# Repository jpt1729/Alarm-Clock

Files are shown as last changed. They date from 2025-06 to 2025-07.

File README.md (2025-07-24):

# Alarm-Clock

Custom built alarm clock. I was partly inspired by this https://busy.bar/. I also just wanted ot make a cool custom project and right now I only have an Alexa next to my bed so I can't actually see the current time, but with this it should both wake me up and it should tell me the time :) 

What this basically is its an ESP32 controlled alarm clock that connects to Wifi has a 1.9" LCD display and a snooze bar. It serves as a clock and an alarm (as of now, but I want to program it a bit more in the future!)

When I first learned about making PCBs this (along with a keyboard [which I already made!]) was one of the projects I wanted to try my hand at so I am happy I got to do it!

The plan to make the case a bit easier to print is to print the top part out and then the bottom part out and connect the two with a soldering iron. This will use a lot less plastic (if not I will basically be printing a solid block of plastic).

# Photos






# BOM

| Item | Quantity Used | Quantity Purchased | Designator | Part Number / Description | Link | Cost |
|---|---|---|---|---|---|---|
| Case | 1 | | | Custom Case | | |
| PCB | 1 | 5 | | Custom PCB | | $8.90 |
| JST Connector | 4 | 5 | | JST-XH-A 5 | [LCSC](https://lcsc.com/product-detail/Wire-To-Board-Connector_JST-B5B-XH-A-LF-SN_C157991.html) | $0.42 |
| JST Connector | 2 | 5 | | JST-XH-A 8 | [LCSC](https://lcsc.com/product-detail/Wire-To-Board-Connector_JST-B8B-XH-A-LF-SN_C157972.html) | $0.66 |
| MCU | 1 | 1 | | ESP-32-S3-MINI-1 | [LCSC](https://lcsc.com/product-detail/WiFi-Modules_Espressif-Systems-ESP32-S3-MINI-1-N8_C2913206.html) | $5.11 |
| Buzzer | 2 | 5 | | TMB12A05 | [LCSC](https://lcsc.com/product-detail/Buzzers_Jiangsu-Huaneng-Elec-TMB12A05_C96093.html) | $0.90 |
| Capacitor | 1 | 100 | C1 | 0603 1uF (100nF) | [LCSC](https://lcsc.com/product-detail/image/CC0603KRX7R9BB104_C14663.html) | $0.24 |
| USB Connector | 1 | 1 | J1 | USB-C USB4105-GF-A | [LCSC](https://lcsc.com/product-detail/USB-Connectors_Global-Connector-Technology-USB4105-GF-A_C3020560.html) | $1.16 |
| LCD Display | 1 | 10 | | 1.9" LCD | [AliExpress](https://www.aliexpress.us/item/3256807182983606.html) | $3.25 |
| Diodes | 2 | 10 | | 40V 200mA NPN TO-92 | [LCSC](https://lcsc.com/product-detail/image/2N3904X_C5156722.html) | $0.38 |
| Resistor | 1 | 100 | R1 | 10k Ohm 0603 | [LCSC](https://lcsc.com/product-detail/image/RC0603FR-0710KL_C98220.html) | $0.11 |
| Resistor | 2 | 100 | R2, R3 | 5.1k Ohm 0603 | [LCSC](https://lcsc.com/product-detail/image/RC0603FR-075K1L_C105580.html) | $0.12 |
| Resistor | 2 | 100 | R4, R5 | 1k Ohm 0603 | [LCSC](https://lcsc.com/product-detail/Chip-Resistor-Surface-Mount_YAGEO-RC0603FR-071KL_C22548.html) | $0.11 |
| Switch | 1 | 10 | SW1 | Gateron Low Profile | [AliExpress](https://www.aliexpress.us/item/3256808635477539.html) | $5.79 |
| Encoder | 1 | 5 | ENC1 | EC11 Rotary Encoder | [AliExpress](https://www.aliexpress.us/item/3256801237549169.html) | $0.99 |
| Voltage Regulator | 1 | 5 | U1 | AMS1117-3.3 | [LCSC](https://lcsc.com/product-detail/Voltage-Regulators-Linear-Low-Drop-Out-LDO-Regulators_Advanced-Monolithic-Systems-AMS1117-3-3_C6186.html) | $0.87 |
| SXH-001T-P0.6 | | 100 | | Terminal pin (x100) | [LCSC](https://lcsc.com/product-detail/Housing-Contact_JST-SXH-001T-P0-6_C140573.html) | $1.08 |
| XHP-5 | | 20 | | 5-pin housing (x20) | [LCSC](https://lcsc.com/product-detail/Housings-Wire-To-Board-Wire-To-Wire_JST-XHP-5_C144404.html) | $0.46 |
| XHP-8 | | 20 | | 8-pin housing (x20) | [LCSC](https://lcsc.com/product-detail/Housings-Wire-To-Board-Wire-To-Wire_JST-XHP-8_C144407.html) | $0.65 |
| Connector Kit (Amazon) | | | | SXH-001T-P0.6, XHP-5, XHP-8 Assortment | [Amazon](https://a.co/d/gTI01NR) | $6.97 |
| Shipping JLC PCB | | | | | | $22.73 |
| Shipping LCSC | | | | | | $17.39 |
| Shipping AliExpress | | | | | | $0.00 |
| Hotplate | 1 | 1 | | Soldering Hotplate | [AliExpress](https://www.aliexpress.us/item/3256806325004979.html) | $20.05 |
| **Total** | | | | | | **$77.72** |

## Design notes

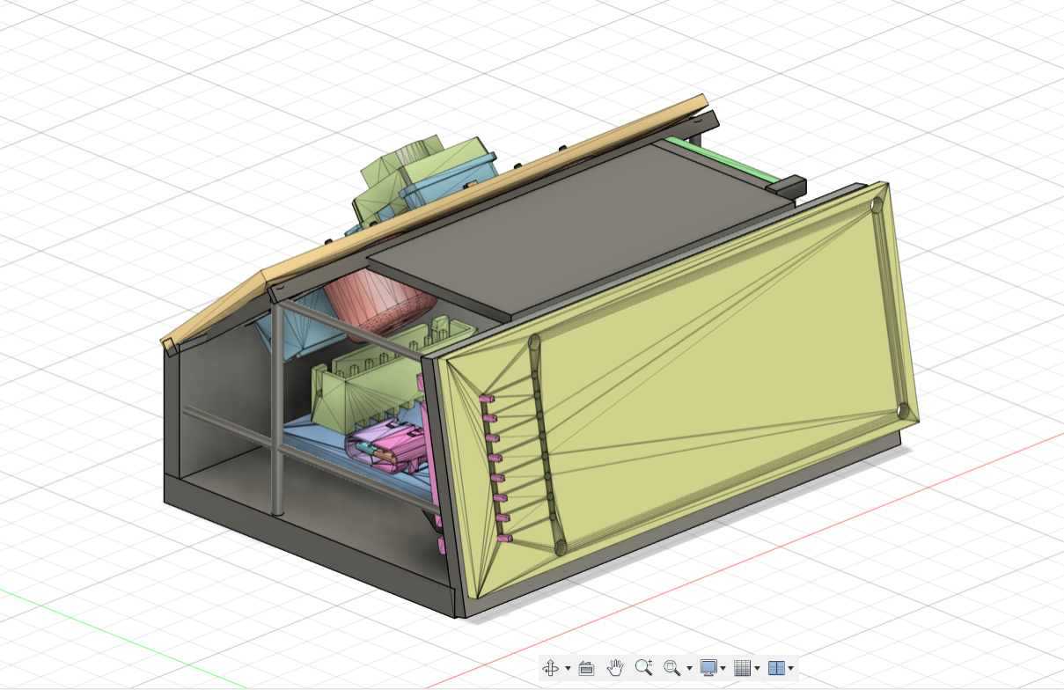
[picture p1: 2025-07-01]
photos/Screenshot 2025-07-01 144503.png

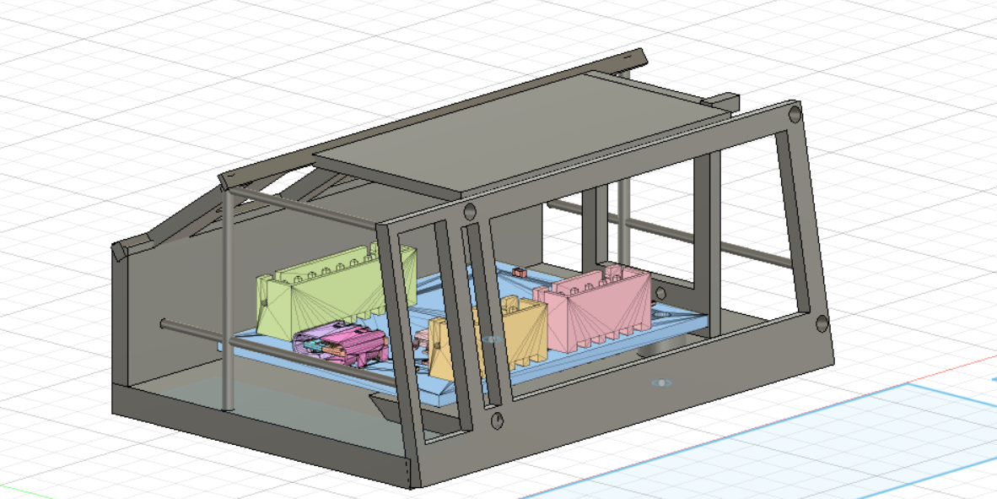
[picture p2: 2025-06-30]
photos/Screenshot 2025-06-30 102602.png

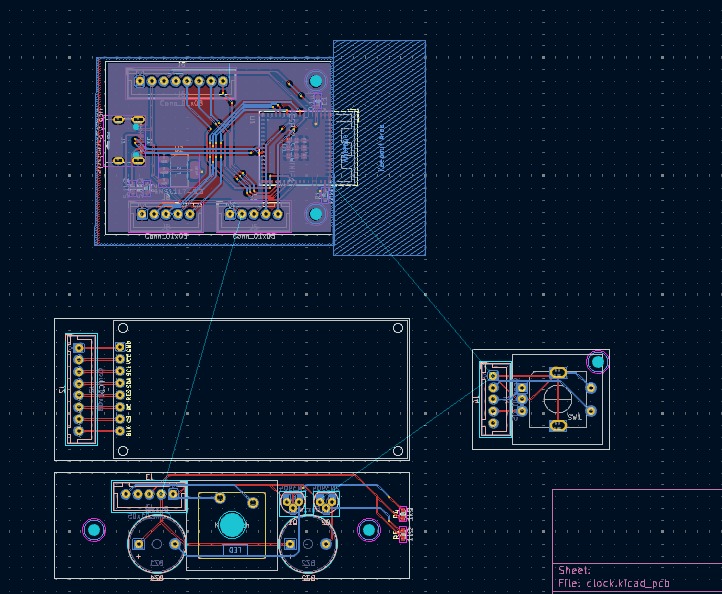
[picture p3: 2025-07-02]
photos/Screenshot 2025-07-01 180052.png

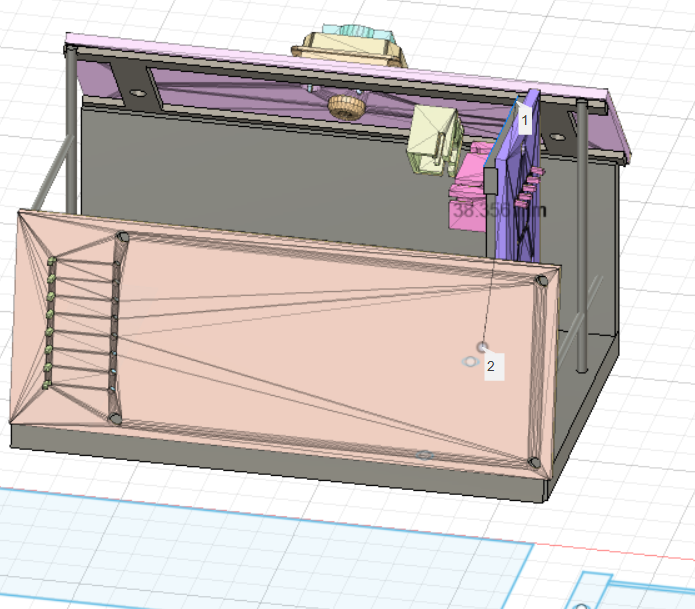
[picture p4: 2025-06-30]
photos/Screenshot 2025-06-30 092751.png

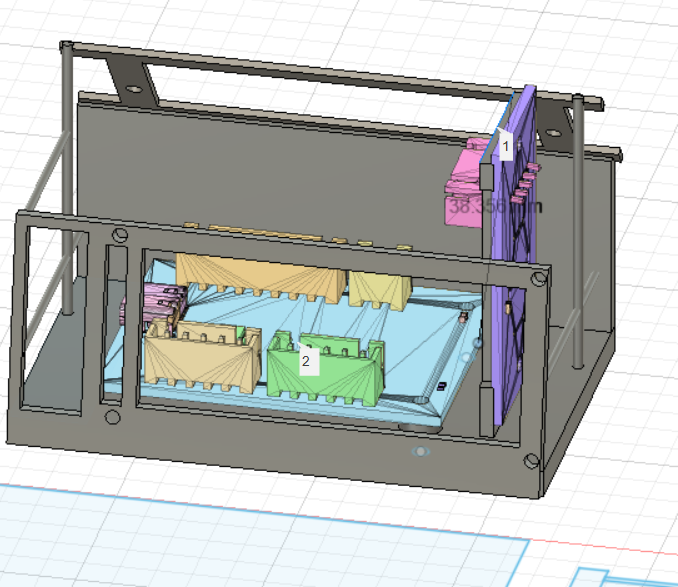
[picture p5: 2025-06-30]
photos/Screenshot 2025-06-30 092739.png

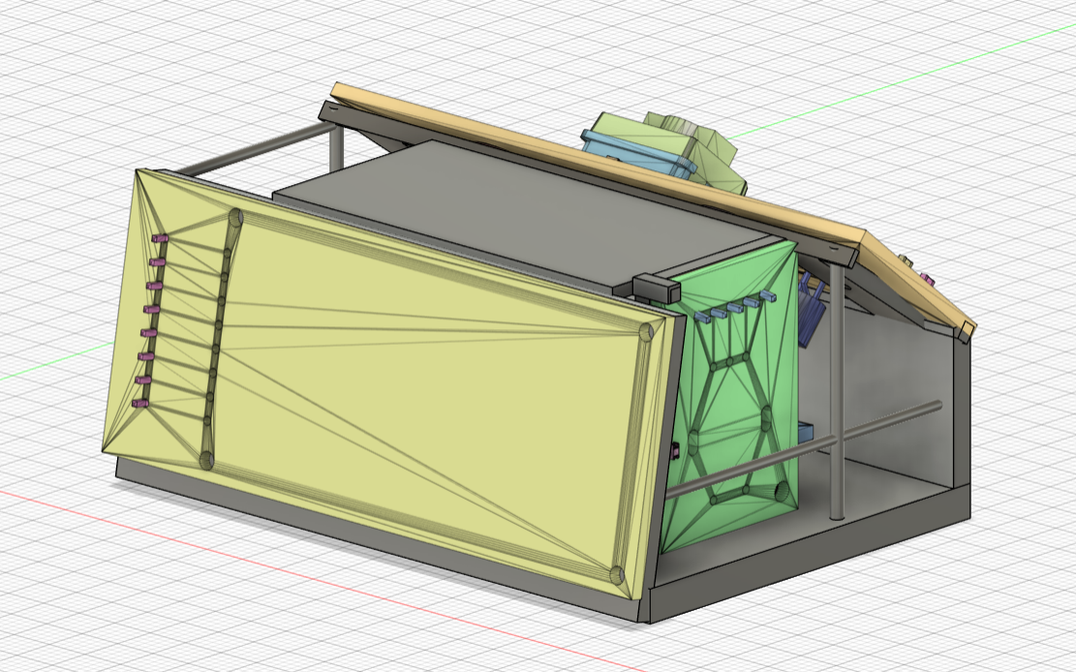
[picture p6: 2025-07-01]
photos/Screenshot 2025-07-01 144437.png

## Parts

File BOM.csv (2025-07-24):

Item | Quantity Used | Quantity Purchased | Designator | Part Number / Description | Link | Cost
Case | 1 |  |  | Custom Case
PCB | 1 | 5 |  | Custom PCB |  | $8.90
JST Connector | 4 | 5 |  | JST-XH-A 5 | https://lcsc.com/product-detail/Wire-To-Board-Connector_JST-B5B-XH-A-LF-SN_C157991.html | $0.42
JST Connector | 2 | 5 |  | JST-XH-A 8 | https://www.google.com/search | $0.66
MCU | 1 | 1 |  | ESP-32-S3-MINI-1 | https://lcsc.com/product-detail/WiFi-Modules_Espressif-Systems-ESP32-S3-MINI-1-N8_C2913206.html | $5.11
Buzzer | 2 | 5 |  | TMB12A05 | https://lcsc.com/product-detail/Buzzers_Jiangsu-Huaneng-Elec-TMB12A05_C96093.html | $0.90
Capacitor | 1 | 100 | C1 | 0603 1uF (100nF) | https://lcsc.com/product-detail/image/CC0603KRX7R9BB104_C14663.html | $0.24
USB Connector | 1 | 1 | J1 | USB-C USB4105-GF-A | https://www.google.com/search | $1.16
LCD Display | 1 | 10 |  | 1.9" LCD | https://www.aliexpress.us/item/3256807182983606.html | $3.25
Diodes | 2 | 10 |  | 40V 200mA NPN TO-92 | https://lcsc.com/product-detail/image/2N3904X_C5156722.html | $0.38
Resistor | 1 | 100 | R1 | 10k Ohm 0603 | https://lcsc.com/product-detail/image/RC0603FR-0710KL_C98220.html | $0.11
Resistor | 2 | 100 | R2, R3 | 5.1k Ohm 0603 | https://lcsc.com/product-detail/image/RC0603FR-075K1L_C105580.html | $0.12
Resistor | 2 | 100 | R4, R5 | 1k Ohm 0603 | https://lcsc.com/product-detail/Chip-Resistor-Surface-Mount_YAGEO-RC0603FR-071KL_C22548.html | $0.11
Switch | 1 | 10 | SW1 | Gateron Low Profile | https://www.aliexpress.us/item/3256808635477539.html | $5.79
Encoder | 1 | 5 | ENC1 | EC11 Rotary Encoder | https://www.aliexpress.us/item/3256801237549169.html | $0.99
Voltage Regulator | 1 | 5 | U1 | AMS1117-3.3 | https://lcsc.com/product-detail/Voltage-Regulators-Linear-Low-Drop-Out-LDO-Regulators_Advanced-Monolithic-Systems-AMS1117-3-3_C6186.html | $0.87
SXH-001T-P0.6 |  | 100 |  | Terminal pin (x100) | https://lcsc.com/product-detail/Housing-Contact_JST-SXH-001T-P0-6_C140573.html | $1.08
XHP-5 |  | 20 |  | 5-pin housing (x20) | https://lcsc.com/product-detail/Housings-Wire-To-Board-Wire-To-Wire_JST-XHP-5_C144404.html | $0.46
XHP-8 |  | 20 |  | 8-pin housing (x20) | https://lcsc.com/product-detail/Housings-Wire-To-Board-Wire-To-Wire_JST-XHP-8_C144407.html | $0.65
Connector Kit (Amazon) |  |  |  |  | SXH-001T-P0.6 | XHP-5 | XHP-8 Assortment | https://a.co/d/gTI01NR | $6.97
Hotplate | 1 | 1 |  | Soldering Hotplate | https://www.aliexpress.us/item/3256806325004979.html | $20.05
Shipping JLC PCB |  |  |  |  |  | $22.73
Shipping LCSC |  |  |  |  |  | $17.39
Shipping AliExpress |  |  |  |  |  | $0.00
Total |  |  |  |  |  | $77.72

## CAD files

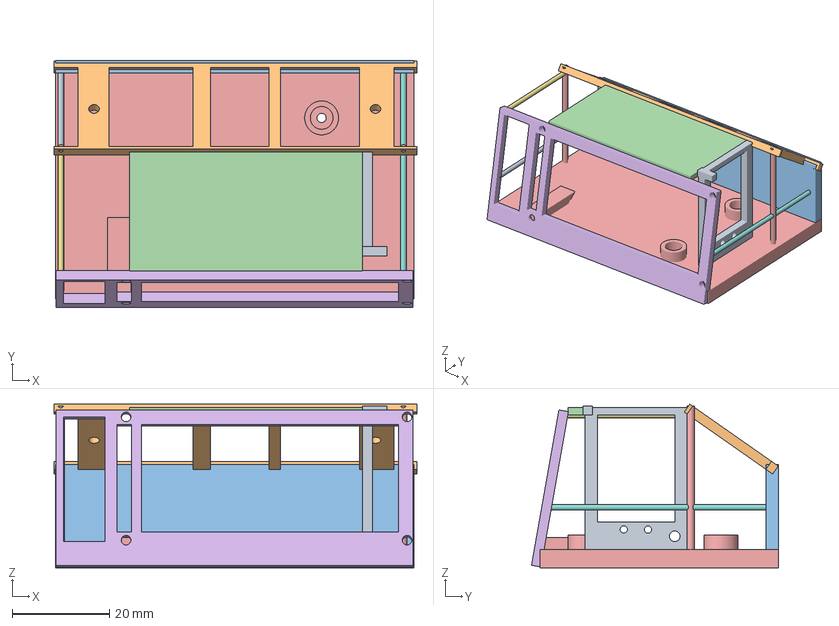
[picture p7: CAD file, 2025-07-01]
CAD/case.3mf
74.8 x 50.9 x 33.7 mm

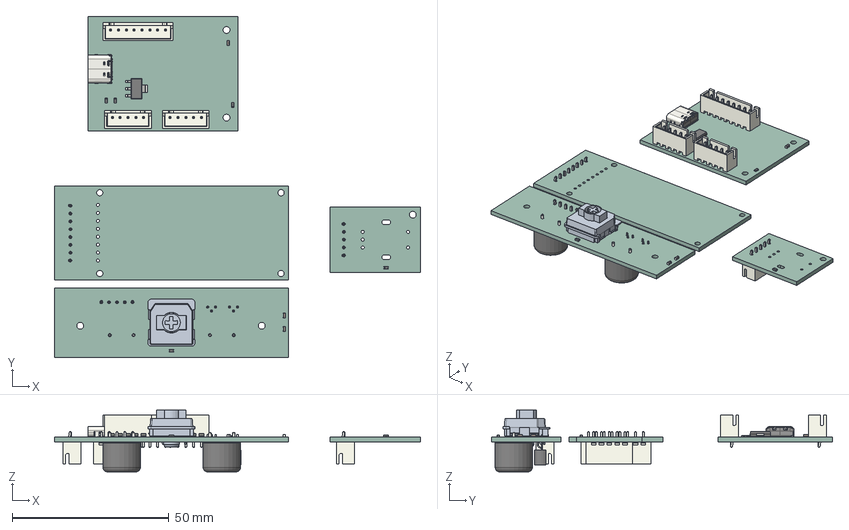
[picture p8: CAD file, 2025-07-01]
PCB/clock.step
117.0 x 108.9 x 19.8 mm
clock 1.1.1
D_0603_1608Metric x 2
JST_XH_B5B-XH-A_1x05_P2.50mm_Vertical x 4
C_0603_1608Metric x 3
JST_XH_B8B-XH-A_1x08_P2.50mm_Vertical x 2
R_0603_1608Metric x 3
SOT-223
USB_C_Receptacle_GCT_USB4105-xx-A_16P_TopMnt_Horizontal
TO-92 x 2
Buzzer_12x9.5RM7.6 x 2
clock_PCB_1
clock_PCB_2
clock_PCB_3
clock_PCB_4

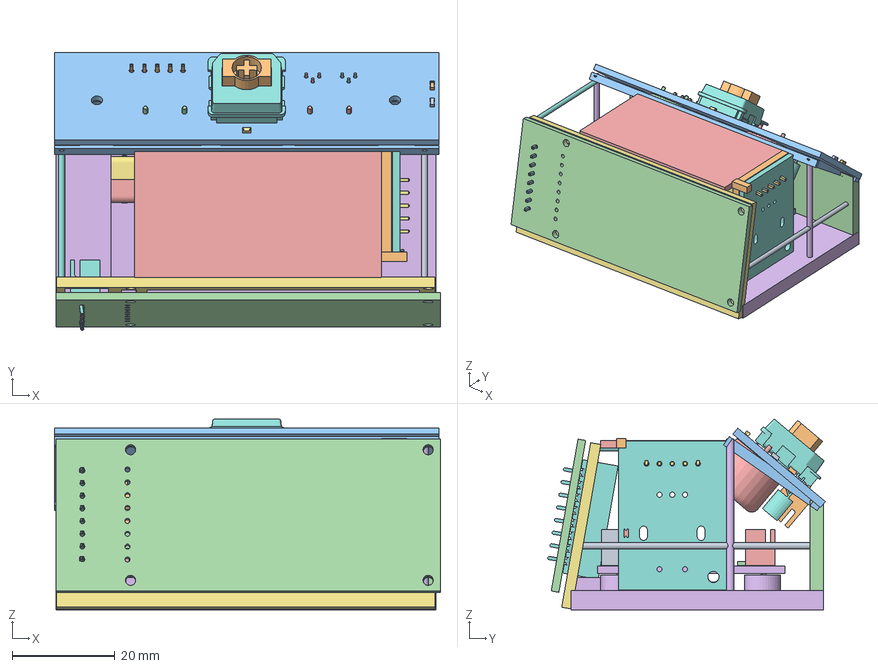
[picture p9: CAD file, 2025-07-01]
CAD/clock+pcb.3mf
75.1 x 54.1 x 37.2 mm
clock_PCB_2
D_0603_1608Metric (1)
clock_PCB_3
C_0603_1608Metric (1)
SOT-223
TO-92 (1)
R_0603_1608Metric (2)
R_0603_1608Metric
JST_XH_B5B-XH-A_1x05_P2.50mm_Vertical (3)
JST_XH_B8B-XH-A_1x08_P2.50mm_Vertical
JST_XH_B8B-XH-A_1x08_P2.50mm_Vertical (1)
Buzzer_12x9.5RM7.6 (1)
JST_XH_B5B-XH-A_1x05_P2.50mm_Vertical
C_0603_1608Metric (2)
D_0603_1608Metric
C_0603_1608Metric
JST_XH_B5B-XH-A_1x05_P2.50mm_Vertical (1)
clock_PCB_1
Buzzer_12x9.5RM7.6
clock_PCB_4
JST_XH_B5B-XH-A_1x05_P2.50mm_Vertical (2)
TO-92
R_0603_1608Metric (1)

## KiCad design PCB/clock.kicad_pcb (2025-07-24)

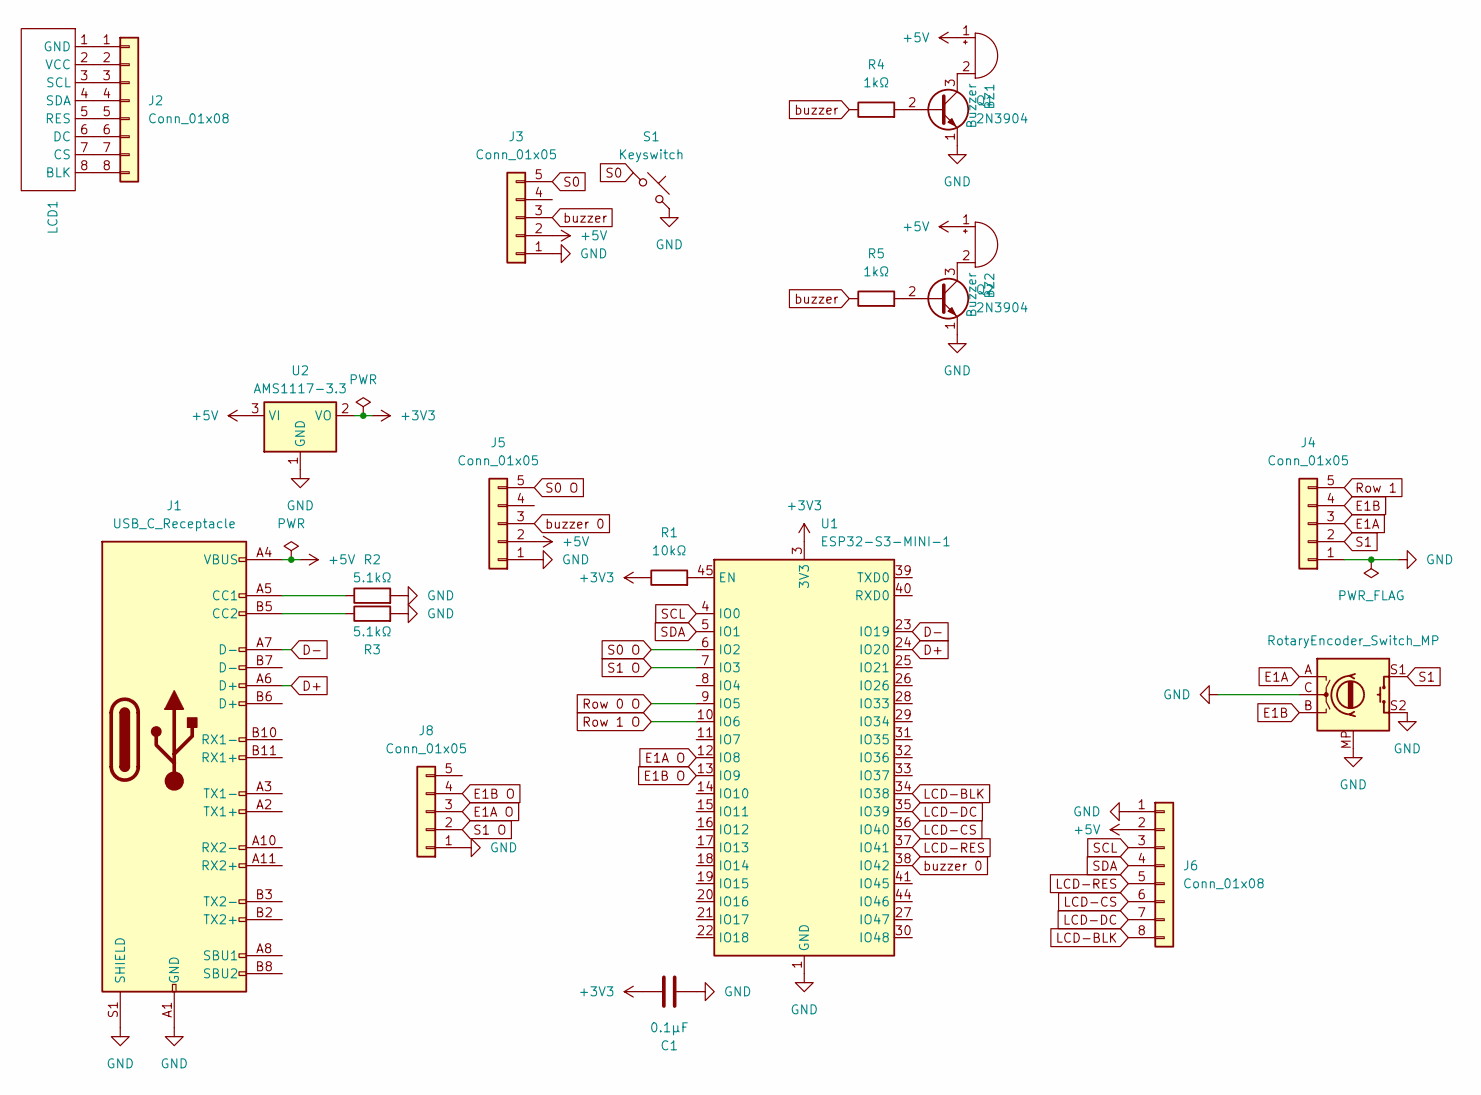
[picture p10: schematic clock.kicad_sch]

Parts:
BZ1, BZ2: Buzzer; Buzzer_12x9.5RM7.6
C1: 0.1µF; C_0603_1608Metric_Pad1.08x0.95mm_HandSolder
J1: USB_C_Receptacle; USB_C_Receptacle_GCT_USB4105-xx-A_16P_TopMnt_Horizontal
J2, J6: Conn_01x08; JST_XH_B8B-XH-A_1x08_P2.50mm_Vertical
J3, J4, J5, J8: Conn_01x05; JST_XH_B5B-XH-A_1x05_P2.50mm_Vertical
LCD1: TZT_1.9in_TFT_ST7789
Q1, Q2: 2N3904; TO-92_HandSolder
R1: 10kΩ; R_0603_1608Metric_Pad0.98x0.95mm_HandSolder
R2, R3: 5.1kΩ; R_0603_1608Metric_Pad0.98x0.95mm_HandSolder
R4, R5: 1kΩ; C_0603_1608Metric_Pad1.08x0.95mm_HandSolder
S1: Keyswitch; SW_KS33_1u
SW1: RotaryEncoder_Switch_MP; Encoder_EC11_MX
U1: ESP32-S3-MINI-1; ESP32-S2-MINI-1
U2: AMS1117-3.3; SOT-223-3_TabPin2

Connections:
+3V3: C1.2, R1.1, U1.3 (3V3), U2.2 (VO)
+5V: BZ1.1 (+), BZ2.1 (+), J1.A4 (VBUS), J1.A9 (VBUS), J1.B4 (VBUS), J1.B9 (VBUS), J3.2, J5.2, J6.2, U2.3 (VI)
D+: J1.A6 (D+), U1.24 (IO20)
D-: J1.A7 (D-), U1.23 (IO19)
E1A: J4.3, SW1.A
E1A O: J8.3, U1.12 (IO8)
E1B: J4.4, SW1.B
E1B O: J8.4, U1.13 (IO9)
GND: C1.1, J1.A1 (GND), J1.A12 (GND), J1.B1 (GND), J1.B12 (GND), J1.S1 (SHIELD), J3.1, J4.1, J5.1, J6.1, J8.1, Q1.1 (E), Q2.1 (E), R2.2, R3.2, S1.2, SW1.C, SW1.MP, SW1.S2, U1.1 (GND), U1.2 (GND), U1.42 (GND), U1.43 (GND), U1.46 (GND), U1.47 (GND), U1.48 (GND), U1.49 (GND), U1.50 (GND), U1.51 (GND), U1.52 (GND), U1.53 (GND), U1.54 (GND), U1.55 (GND), U1.56 (GND), U1.57 (GND), U1.58 (GND), U1.59 (GND), U1.60 (GND), U1.61 (GND), U1.62 (GND), U1.63 (GND), U1.64 (GND), U1.65 (GND), U2.1 (GND)
LCD-BLK: J6.8, U1.34 (IO38)
LCD-CS: J6.6, U1.36 (IO40)
LCD-DC: J6.7, U1.35 (IO39)
LCD-RES: J6.5, U1.37 (IO41)
unnamed: BZ1.2 (-), Q1.3 (C)
unnamed: BZ2.2 (-), Q2.3 (C)
unnamed: J1.A5 (CC1), R2.1
unnamed: J1.B5 (CC2), R3.1
unnamed: J2.1, LCD1.1 (GND)
unnamed: J2.2, LCD1.2 (VCC)
unnamed: J2.3, LCD1.3 (SCL)
unnamed: J2.4, LCD1.4 (SDA)
unnamed: J2.5, LCD1.5 (RES)
unnamed: J2.6, LCD1.6 (DC)
unnamed: J2.7, LCD1.7 (CS)
unnamed: J2.8, LCD1.8 (BLK)
unnamed: Q1.2 (B), R4.2
unnamed: Q2.2 (B), R5.2
unnamed: R1.2, U1.45 (EN)
Row 0 O: U1.9 (IO5)
Row 1: J4.5
Row 1 O: U1.10 (IO6)
S0: J3.5, S1.1
S0 O: J5.5, U1.6 (IO2)
S1: J4.2, SW1.S1
S1 O: J8.2, U1.7 (IO3)
SCL: J6.3, U1.4 (IO0)
SDA: J6.4, U1.5 (IO1)
buzzer: J3.3, R4.1, R5.1
buzzer 0: J5.3, U1.38 (IO42)

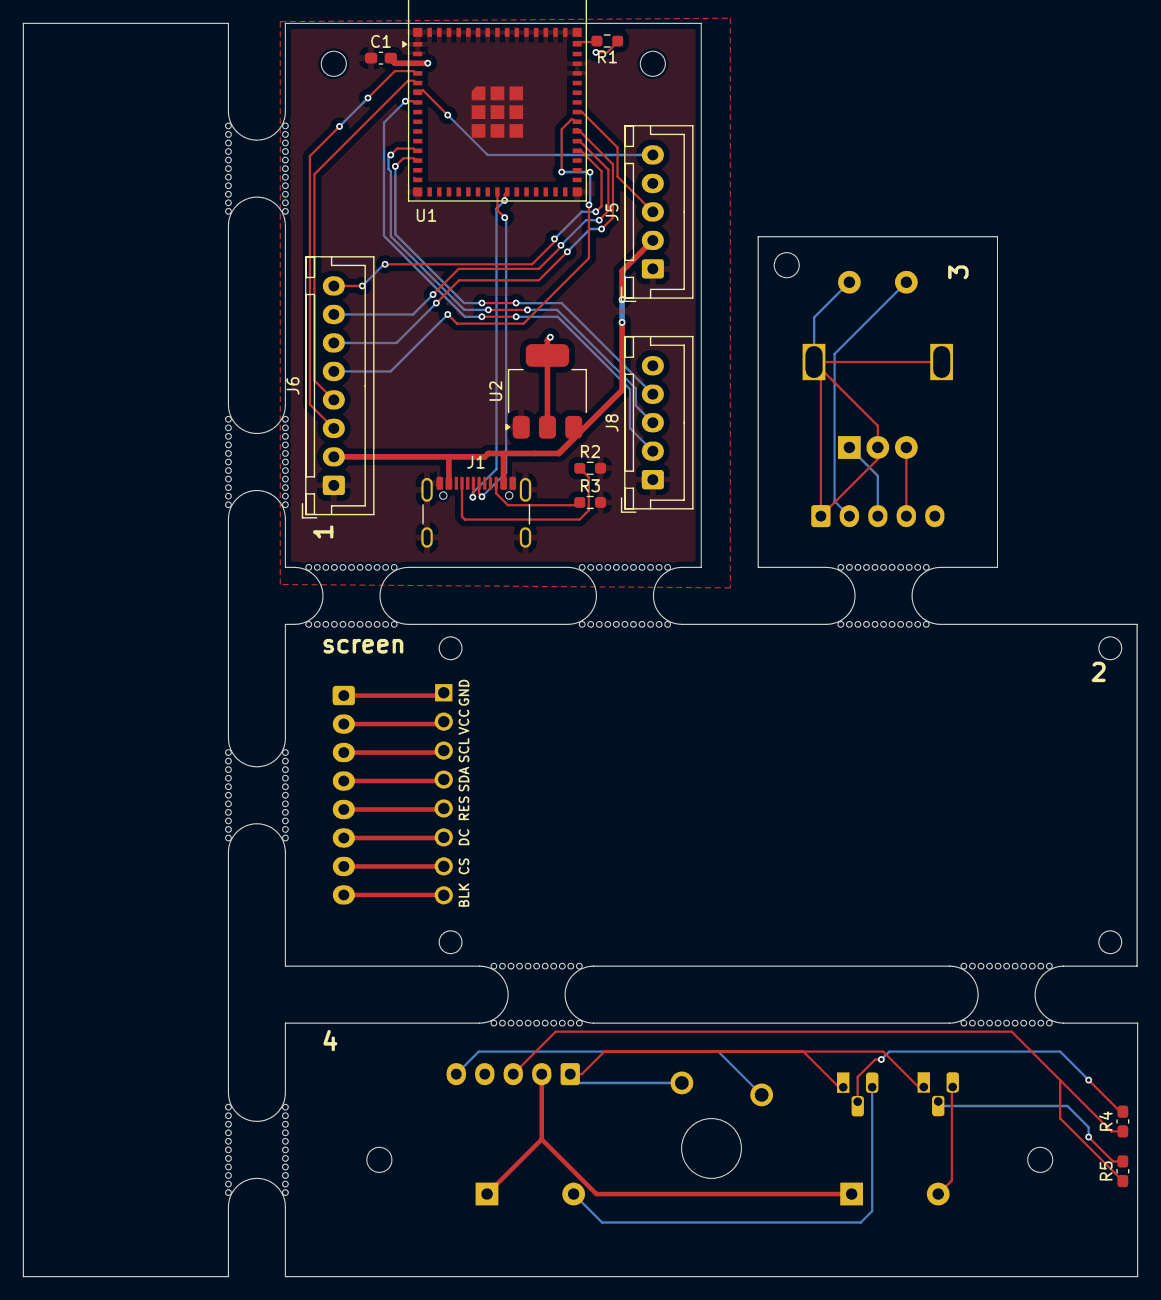
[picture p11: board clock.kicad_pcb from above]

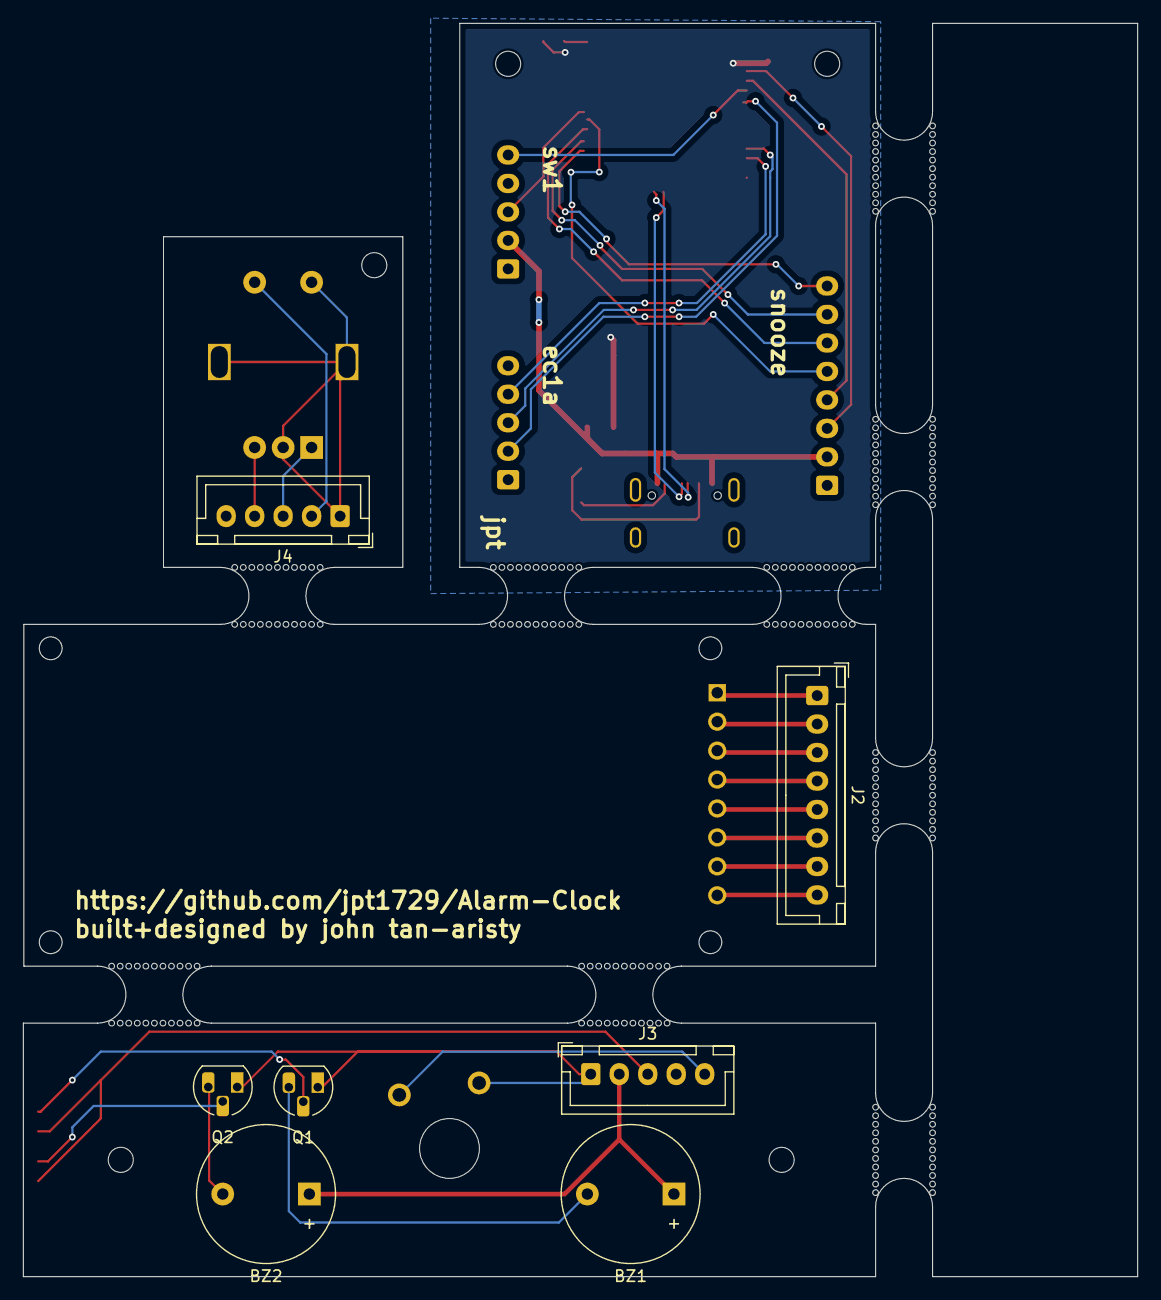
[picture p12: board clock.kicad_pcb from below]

Board: 2 copper layers, 97.8 x 110.0 mm, 31 parts (7 on the bottom side), 36 nets.

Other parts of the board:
mouse-bite-5mm-slot, mouse-bite-5mm-slot#2, mouse-bite-5mm-slot#3, mouse-bite-5mm-slot#4, mouse-bite-5mm-slot#5, mouse-bite-5mm-slot#6, mouse-bite-5mm-slot#7, mouse-bite-5mm-slot#8, mouse-bite-5mm-slot#9: VAL**; mouse-bite-5mm-slot

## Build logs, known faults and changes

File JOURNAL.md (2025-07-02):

---
title: "Alarm Clock"
author: "John"
description: "Alarm clock with an LCD display and a speaker."
created_at: "2025-06-04"
---

Wanted to note, I had no idea we had to write down the hours we worked on it so I just estimated the hours it took after the fact. I would say the total time I spend on this project is in the ~15 hr range.

# June 26th
Its important to me that this thing is kinda cools so I am thinking of some features I want it to have
- google calendar integration where it wakes me up 30 minutes before the first event on my calendar
- Gives me a preview of my day and everything I gotta do (all the stuff on my calendar)

Still thinking of some features but planning on writing those as I go.

Picked out a couple of the parts I know I want to use like an esp32-s3-mini as the main board thing.

**Total time spent: 30min**

# June 29th
Haven't updated in a while but i finished my schematic so far and my pcb. The design is currently 4 different pcb modules which will all be connected by cables so I can create a "3d case." One module for the main board with the ESP32-s3-mini, another one for the snooze button, and 2 rotary encoders.

I am in a bit of a rush to get the invite to highway, but yeah.

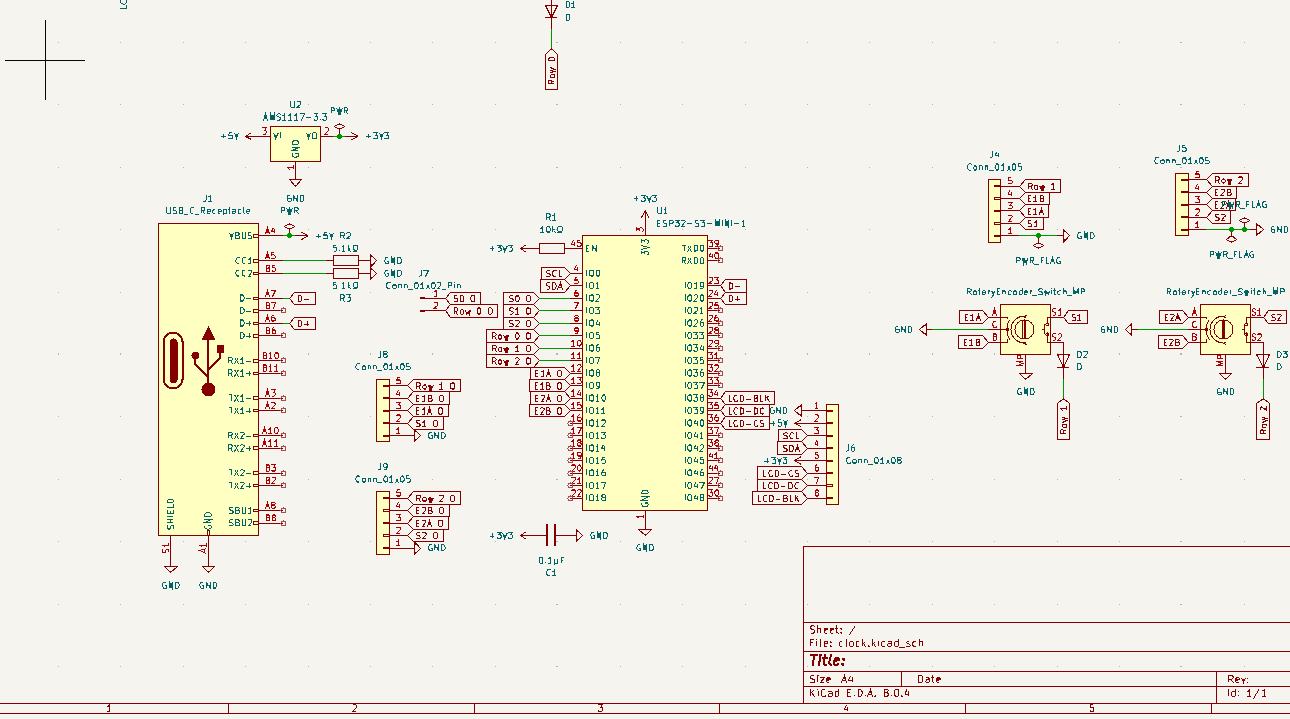
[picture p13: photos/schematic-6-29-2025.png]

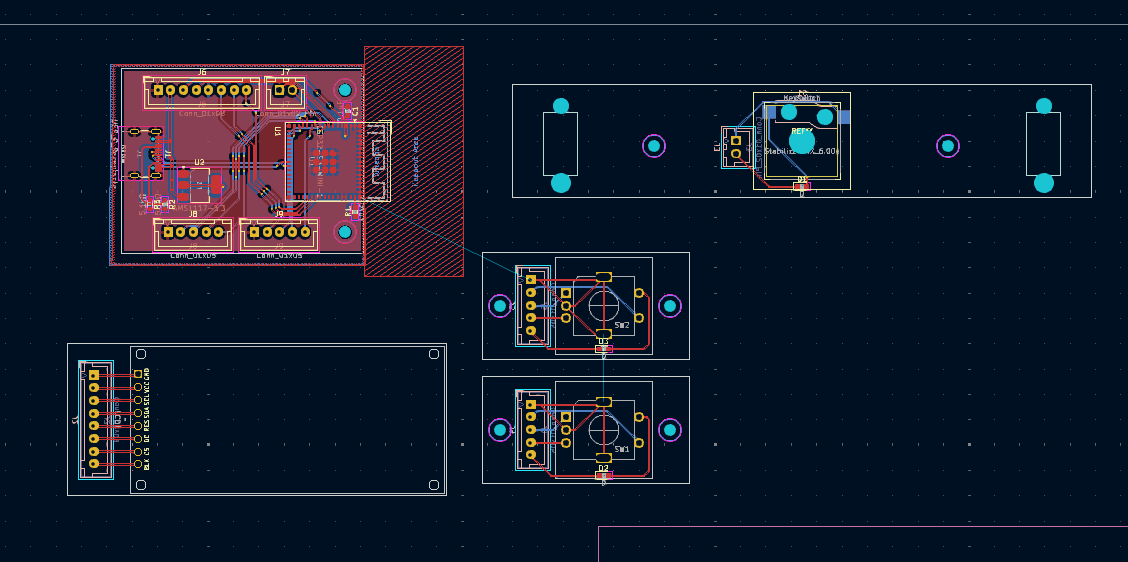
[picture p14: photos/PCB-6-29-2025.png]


The PCB has some errors and for some reason says I need to connect the ground even though there is a powerflag, but those are issues I feel fine ignoring lol.

I am starting to work on the case in fusion360.

**Total time spent: 3.5hrs**

# June 30th

I've been starting to work on the case and I realised that 2 ec11 encoders doesn't really make any sense and that the current structure makes the clock look werid lol.

I have to do some redesign to support the buzzer which will wake me up. Its going to be on the snooze bar and there will be 2 big of them.

I also made a mistake and accidentally deleted the correct copy of the pcb 🤦‍♂️🤦‍♂️🤦‍♂️ so now I gotta redo some sizing changes and stuff.




Here is the before. As you can see the dial on the side is just too tall this is because I had 2 screws to secure it. Now it is only one with a hook at the top to make sure it doesn't moove and shake around.

Here it is now! I like the cases structure and how it looks ngl.


Some stuff I added are beepers to help me actually wake up they are placed on the snooze button (Not sure if you can see them but they are there)
After this, I have only the hard part which is just making the code!

**Total time spent: 4hrs**

# July 1st

I've just started finishing up my 3d modeling and stuff and now I am going to work on the firmware.

I am going to use circuit python just because I have the most experience with that

Some goals for today
- build out a beeper function
- properly display time
- schedule alarms properly
- maybe google calendar integration?? (this is kinda gunna be hard)

Ok now I finished all those and built everything besides the google calendar integration, but I think this is ready to submit?

Just finished my readme and added the BOM. 





Fusion 360 updated while I was working on this project and now it looks so much nicer!

**Total time spent: 4hrs**

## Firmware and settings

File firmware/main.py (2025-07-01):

import board
import displayio
import terminalio
from adafruit_display_text import label
from fourwire import FourWire
from adafruit_st7789 import ST7789
import time
import rtc
import digitalio
import rotaryio
import wifi
import socketpool
import adafruit_ntp

# Release any resources currently in use for the displays
displayio.release_displays()

# WiFi Configuration
WIFI_SSID = "YOUR_WIFI_SSID"  # TODO: Update with your WiFi name
WIFI_PASSWORD = "YOUR_WIFI_PASSWORD"  # TODO: Update with your WiFi password

# Setup buzzer
buzzer = digitalio.DigitalInOut(board.IO42)
buzzer.direction = digitalio.Direction.OUTPUT
buzzer.value = False  # Start with buzzer off

# Setup buttons
alarm_set_button = digitalio.DigitalInOut(board.IO3)
alarm_set_button.direction = digitalio.Direction.INPUT
alarm_set_button.pull = digitalio.Pull.UP

snooze_button = digitalio.DigitalInOut(board.IO2)
snooze_button.direction = digitalio.Direction.INPUT
snooze_button.pull = digitalio.Pull.UP

# Setup encoder
encoder = rotaryio.IncrementalEncoder(board.IO8, board.IO9)

spi = board.SPI()
tft_cs = board.IO40
tft_dc = board.IO39
tft_rst = board.IO41 

display_bus = FourWire(spi, command=tft_dc, chip_select=tft_cs, reset=tft_rst)

display = ST7789(display_bus, width=320, height=170, colstart=35, rotation=90)

# Make the display context
splash = displayio.Group()
display.root_group = splash

# Initialize RTC
rtc_instance = rtc.RTC()

# Set initial time (will be updated by NTP)
# Format: (year, month, day, hour, minute, second, weekday, yearday)
rtc_instance.datetime = time.struct_time((2024, 1, 1, 12, 0, 0, 0, 1, -1))

# Alarm variables
alarm_hour = 7
alarm_minute = 0
alarm_enabled = False
alarm_ringing = False
snooze_time = None
snooze_duration = 9 * 60  # 9 minutes in seconds

# Display mode
setting_alarm = False
setting_hour = True  # True for hour, False for minute

# WiFi and sync variables
wifi_connected = False
last_sync = 0
sync_interval = 3600  # Sync every hour

# Create time label
time_label = label.Label(
    terminalio.FONT,
    text="",
    color=0xFFFFFF,  # White text
    scale=4,
    anchor_point=(0.5, 0.5),
    anchored_position=(display.width // 2, display.height // 2),
)
splash.append(time_label)

# Create date label (smaller, below time)
date_label = label.Label(
    terminalio.FONT,
    text="",
    color=0xFFFFFF,  # White text
    scale=2,
    anchor_point=(0.5, 0.5),
    anchored_position=(display.width // 2, display.height // 2 + 80),
)
splash.append(date_label)

# Create alarm status label
alarm_label = label.Label(
    terminalio.FONT,
    text="",
    color=0x00FF00,  # Green text
    scale=1,
    anchor_point=(0.5, 0.5),
    anchored_position=(display.width // 2, 20),
)
splash.append(alarm_label)

def connect_wifi():
    """Connect to WiFi and sync time with NTP"""
    try:
        # Show connecting message
        time_label.text = "Connecting..."
        date_label.text = "to WiFi"
        alarm_label.text = ""
        
        # Connect to WiFi
        wifi.radio.start_ap("AlarmClock", "password123")
        wifi.radio.stop_ap()
        wifi.radio.connect(WIFI_SSID, WIFI_PASSWORD)
        
        # Show connected message
        time_label.text = "Connected!"
        date_label.text = "Syncing time..."
        time.sleep(1)
        
        # Setup NTP
        pool = socketpool.SocketPool(wifi.radio)
        ntp = adafruit_ntp.NTP(pool, tz_offset=-6)  # CST timezone
        
        # Get time from NTP
        ntp_time = ntp.datetime
        rtc_instance.datetime = ntp_time
        
        # Show success message
        time_label.text = "Time Synced!"
        date_label.text = format_date(rtc_instance.datetime)
        time.sleep(2)
        
        return True
        
    except Exception as e:
        # Show error message
        time_label.text = "WiFi Error"
        date_label.text = "Check settings"
        alarm_label.text = str(e)[:20]  # Show first 20 chars of error
        time.sleep(3)
        return False

def sync_time():
    """Sync time with NTP server"""
    try:
        pool = socketpool.SocketPool(wifi.radio)
        ntp = adafruit_ntp.NTP(pool, tz_offset=0)  # Change 0 to your timezone
        ntp_time = ntp.datetime
        rtc_instance.datetime = ntp_time
        return True
    except:
        return False

def turn_buzzer_on():
    """Turn on the buzzer"""
    buzzer.value = True

def turn_buzzer_off():
    """Turn off the buzzer"""
    buzzer.value = False

def buzz_alarm(duration=5):
    """Buzz the alarm for a specified duration in seconds"""
    turn_buzzer_on()
    time.sleep(duration)
    turn_buzzer_off()

def format_time(t):
    """Format time as HH:MM AM/PM"""
    hour = t.tm_hour
    minute = t.tm_min
    
    # Convert to 12-hour format
    if hour == 0:
        hour = 12
        ampm = "AM"
    elif hour < 12:
        ampm = "AM"
    elif hour == 12:
        ampm = "PM"
    else:
        hour -= 12
        ampm = "PM"
    
    return f"{hour:02d}:{minute:02d} {ampm}"

def format_date(t):
    """Format date as Month DD, YYYY"""
    months = ["", "Jan", "Feb", "Mar", "Apr", "May", "Jun", 
              "Jul", "Aug", "Sep", "Oct", "Nov", "Dec"]
    return f"{months[t.tm_mon]} {t.tm_mday}, {t.tm_year}"

def format_alarm_time():
    """Format alarm time as HH:MM AM/PM"""
    hour = alarm_hour
    minute = alarm_minute
    
    # Convert to 12-hour format
    if hour == 0:
        hour = 12
        ampm = "AM"
    elif hour < 12:
        ampm = "AM"
    elif hour == 12:
        ampm = "PM"
    else:
        hour -= 12
        ampm = "PM"
    
    return f"{hour:02d}:{minute:02d} {ampm}"

def check_alarm():
    """Check if alarm should go off"""
    global alarm_ringing, snooze_time
    
    if not alarm_enabled and snooze_time is None:
        return
    
    now = rtc_instance.datetime
    current_time = now.tm_hour * 60 + now.tm_min
    
    # Check regular alarm
    if alarm_enabled and not alarm_ringing:
        alarm_time = alarm_hour * 60 + alarm_minute
        if current_time == alarm_time and now.tm_sec == 0:
            alarm_ringing = True
            turn_buzzer_on()
    
    # Check snooze alarm
    if snooze_time is not None and not alarm_ringing:
        snooze_hour = snooze_time // 60
        snooze_minute = snooze_time % 60
        snooze_current = snooze_hour * 60 + snooze_minute
        if current_time == snooze_current and now.tm_sec == 0:
            alarm_ringing = True
            turn_buzzer_on()

def handle_buttons():
    """Handle button presses"""
    global setting_alarm, setting_hour, alarm_enabled, alarm_ringing, snooze_time
    
    # Alarm set button (first button)
    if not alarm_set_button.value:  # Button pressed (active low)
        time.sleep(0.1)  # Debounce
        if not alarm_set_button.value:
            if alarm_ringing:
                # Turn off alarm
                alarm_ringing = False
                turn_buzzer_off()
                snooze_time = None
            elif not setting_alarm:
                # Enter alarm setting mode
                setting_alarm = True
                setting_hour = True
            else:
                # Toggle between hour and minute setting
                if setting_hour:
                    setting_hour = False
                else:
                    # Exit alarm setting mode and enable alarm
                    setting_alarm = False
                    alarm_enabled = True
    
    # Snooze button (second button)
    if not snooze_button.value:  # Button pressed (active low)
        time.sleep(0.1)  # Debounce
        if not snooze_button.value:
            if alarm_ringing:
                # Snooze for 9 minutes
                alarm_ringing = False
                turn_buzzer_off()
                now = rtc_instance.datetime
                current_minutes = now.tm_hour * 60 + now.tm_min
                snooze_time = (current_minutes + 9) % (24 * 60)  # Wrap around midnight

def handle_encoder():
    """Handle encoder rotation for alarm setting"""
    global alarm_hour, alarm_minute
    
    if not setting_alarm:
        return
    
    position = encoder.position
    encoder.position = 0  # Reset position
    
    if position != 0:
        if setting_hour:
            # Adjust hour
            alarm_hour = (alarm_hour + position) % 24
        else:
            # Adjust minute
            alarm_minute = (alarm_minute + position) % 60

def update_display():
    """Update the display with current information"""
    now = rtc_instance.datetime
    
    if setting_alarm:
        # Show alarm setting mode
        if setting_hour:
            time_label.text = f"Set Hour: {alarm_hour:02d}"
        else:
            time_label.text = f"Set Min: {alarm_minute:02d}"
        date_label.text = f"Alarm: {format_alarm_time()}"
        alarm_label.text = "SETTING ALARM"
    else:
        # Show normal time
        time_label.text = format_time(now)
        date_label.text = format_date(now)
        
        if alarm_ringing:
            alarm_label.text = "ALARM!"
        elif alarm_enabled:
            alarm_label.text = f"Alarm: {format_alarm_time()}"
        elif snooze_time is not None:
            snooze_hour = snooze_time // 60
            snooze_minute = snooze_time % 60
            alarm_label.text = f"Snooze: {snooze_hour:02d}:{snooze_minute:02d}"
        else:
            alarm_label.text = "No Alarm Set"

last_update = 0
update_interval = 1  # Update every second

# Initial WiFi connection and time sync
wifi_connected = connect_wifi()

while True:
    current_time = time.time()
    
    # Periodic time sync (every hour)
    if wifi_connected and (current_time - last_sync) >= sync_interval:
        if sync_time():
            last_sync = current_time
    
    # Handle input
    handle_buttons()
    handle_encoder()
    
    # Check alarm
    check_alarm()
    
    # Update display every second
    if current_time - last_update >= update_interval:
        update_display()
        last_update = current_time
    
    time.sleep(0.1)  # Small delay to prevent excessive CPU usage

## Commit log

2025-06-29 Rename Screenshot 2025-06-29 170308.png to schematic-6-29-2025
2025-07-01 photos + case + journal entry
    [case.3mf, clock+pcb.3mf]
2025-07-01 ready to submit?
    [clock.kicad_pcb, clock.kicad_sch]
2025-07-01 pcb remove hotswap switch
    [clock.kicad_pcb, clock.kicad_sch]
